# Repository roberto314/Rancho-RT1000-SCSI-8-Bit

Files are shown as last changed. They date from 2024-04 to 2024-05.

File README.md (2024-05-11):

# Rancho-RT1000-SCSI-8-Bit
Recreation of a bootable ISA 8-Bit SCSI Card.

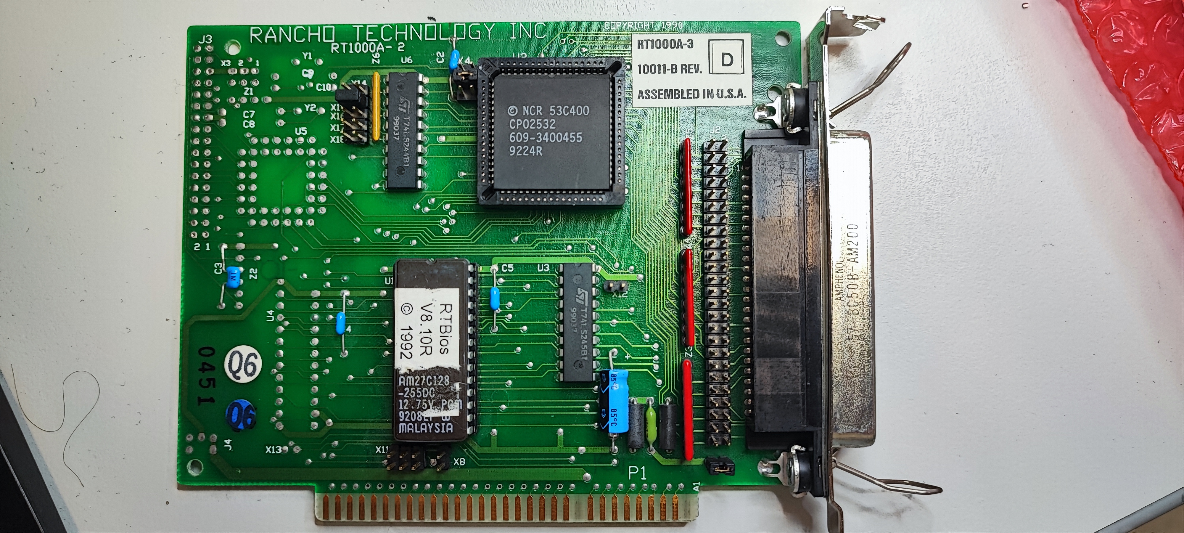
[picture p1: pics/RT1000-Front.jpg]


There can be one PAL on the Card (GAL20L8), this is for the floppy part only.
BIOS EPROM is a 27C128 Type, but only 8k are used.

[Schematic](schematic/Rancho%20RT1000/pdf/Rancho%20RT1000%20SCSI%20Controller.pdf)

For now there is no plan to manufacture the board.

| BIOS Ver. | 8088/80C88 | NEC V20 | 286 |  386SX |
|---|---|---|---|---|
| Rancho 8.10 | no boot, no ASPI | no boot, no ASPI | boots+ASPI | boots+ASPI |
| Rancho 8.20 | no boot, no ASPI | no boot, no ASPI | boots+ASPI | boots+ASPI |
| Corel 1.65  | no boot, Corel ASPI | boots+Corel ASPI | boots+ASPI | boots+ASPI |

Comment: On an XT, even with V20 CPU, with Rancho BIOS, a Disk is found but hangs when trying to boot. RTASPI10.SYS says it needs a 286.

The Card seems to be the same as the Corel LS2000, so i tried the Corel BIOS and it works!

Unfortunately the Corel uses a different CHS Conversion, so the Rancho Images won't work.

The ASPI Driver from the Rancho (RTASPI10.SYS) works with the Corel BIOS and vice versa, BUT they need the correct CHS Values!

The ASPI Driver from the Corel (ASPILS_D.SYS) works with a V20 CPU and with an 8088.
The ASPIDISK.SYS Driver doesn't like the 8088 BUT the Trantor TSCSI Disk Driver in Version 4.53 works (Filename: TSCSI.453)

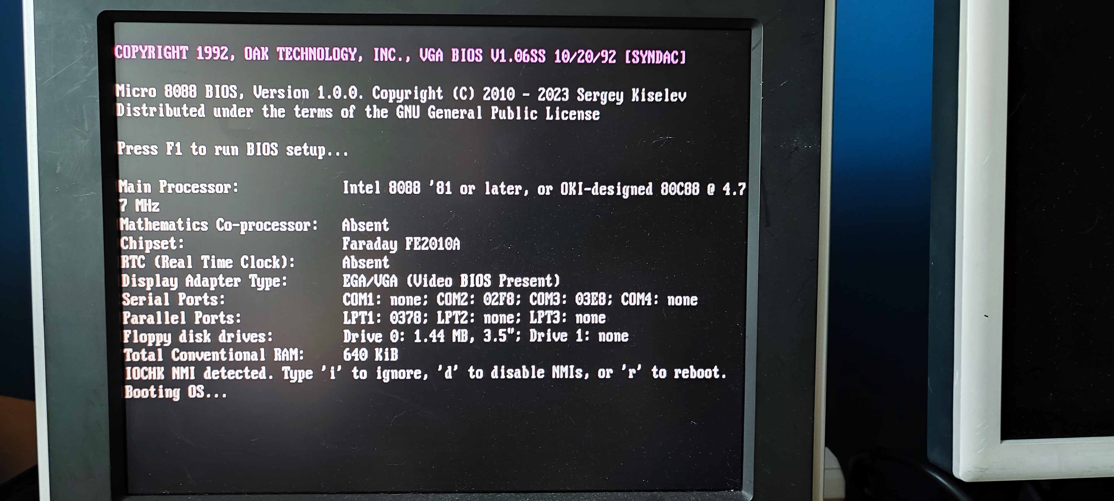
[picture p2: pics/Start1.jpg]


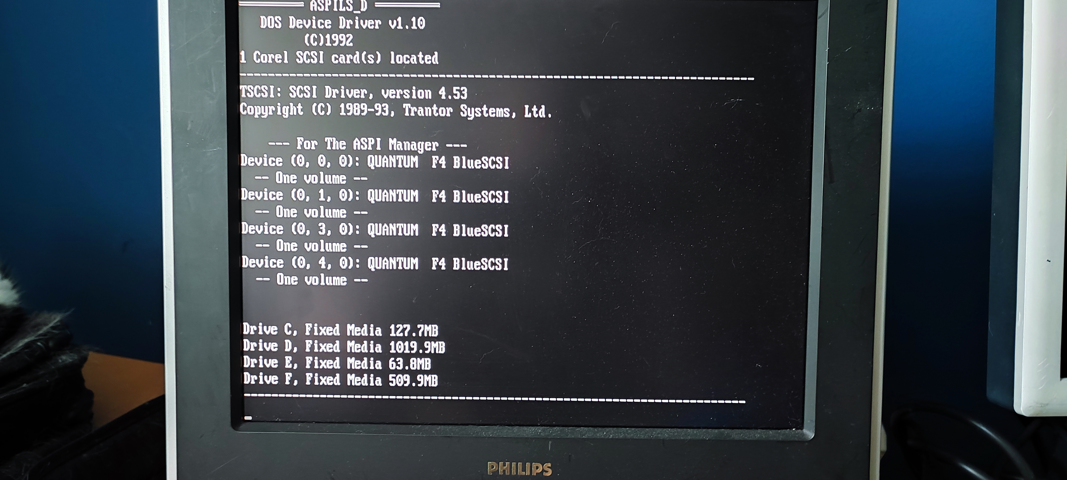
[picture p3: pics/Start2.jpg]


The Rancho BIOS doesn't need an Interrupt, the Corel BIOS seems to work only with IRQ4!
The Jumper X14, X15, X16, X17 and X18 won't do anything with the Corel BIOS.

With the BIOS EPROM installed the 8088 hangs during boot from Floppy! One has to disable the BIOS in order to boot on an 8088.

The Corel BIOS can only address two Harddisks without an ASPI Driver installed!

Heads and Sectors working with original RT1000 BIOS (v8.20):

Tested with MSDOS 5 and with a 386SX and does NOT work with an 8088 nor 80C88!:

(spc = Sectors/Cluster, spf = Sectors/FAT)

* C: 1023 / H:2  / S:32 32 MB (FAT16/4) spc=4,spf=0x40: works
* C: 1023 / H:4  / S:32 64 MB (FAT16/6) spc=4,spf=0x80: non-system disk
* C:  511 / H:8  / S:32 64 MB (FAT16/6) spc=4,spf=0x80: non-system disk
* C: 1015 / H:3  / S:43 65510 kB (FAT16/6) spc=4,spf=0x80: works
* C: 1023 / H:8  / S:32 128 MB (FAT16/6) spc=4,spf=0x100: non-system disk
* C: 1007 / H:5  / S:52 127.8 MB (FAT16/6) spc=4,spf=0x100: works
* C: 1021 / H:9  / S:57 261800 kB (FAT16/6) spc=8,spf=0x100: works
* C: 1023 / H:9  / S:57 262627 kB (FAT16/6) spc=16,spf=0x100: non-system disk
* C: 1010 / H:17  / S:60 515072 kB (FAT16/6) spc=16,spf=0xFC: works
* C: 1011 / H:31  / S:62 948 MB (FAT16/6) spc=32,spf=0xEE: works

Heads and Sectors working with Corel LS2000 BIOS (v1.65):

Tested with 386SX and does NOT work with an 8088!:

* C:  961 / H:17 / S:8 63.1 MB (FAT16/6) spc=4,spf=0x80: works
* C:  961 / H:17 / S:16 127.6 MB (FAT16/6) spc=4,spf=0xFF: works
* C: 1021 / H:32 / S:16 255.5 MB (FAT16/6) spc=16,spf=0x80: works
* C:  597 / H:64 / S:16 299 MB (FAT16/6) spc=16,spf=0x96: works
* C: 1003 / H:64 / S:16 502 MB (FAT16/6) spc=16,spf=0xFB: works
* C: 1019 / H:64 / S:16 509.9 MB (FAT16/6) spc=16,spf=0xFF: works
* C:  570 / H:64 / S:32 570.5 MB (FAT16/6) spc=32,spf=0x8F: works
* C:  571 / H:64 / S:32 572 MB (FAT16/6) spc=32,spf=0x8F: works
* C:  667 / H:64 / S:32 668 MB (FAT16/6) spc=32,spf=0xA7: works
* C:  762 / H:64 / S:32 763 MB (FAT16/6) spc=32,spf=0xBF: works
* C:  859 / H:64 / S:32 860 MB (FAT16/6) spc=32,spf=0xD7: works
* C:  903 / H:64 / S:32 904 MB (FAT16/6) spc=32,spf=0xE2: works
* C:  927 / H:64 / S:32 927.9 MB (FAT16/6) spc=32,spf=0xE8: works
* C: 1019 / H:64 / S:32 1020 MB (FAT16/6) spc=32,spf=0xFF: works
* C:  946 / H:64 / S:32 947 MB (FAT16/6) spc=32,spf=0xED: doesn't work
* C:  946 / H:64 / S:32 947 MB (FAT16/6) spc=32,spf=0xFB: doesn't work

It should be said that the Corel Drivers and BIOS is the way to go!

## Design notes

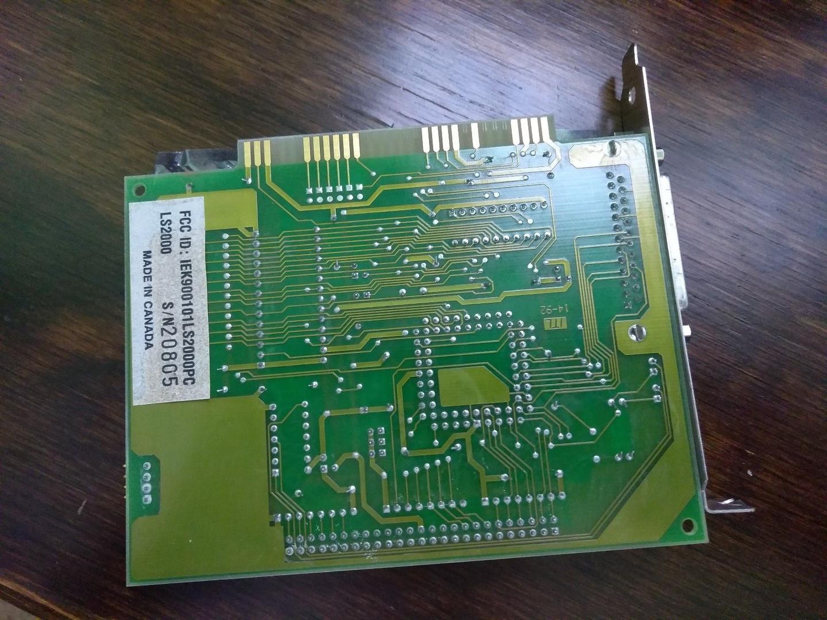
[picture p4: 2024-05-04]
pics/Back.jpg

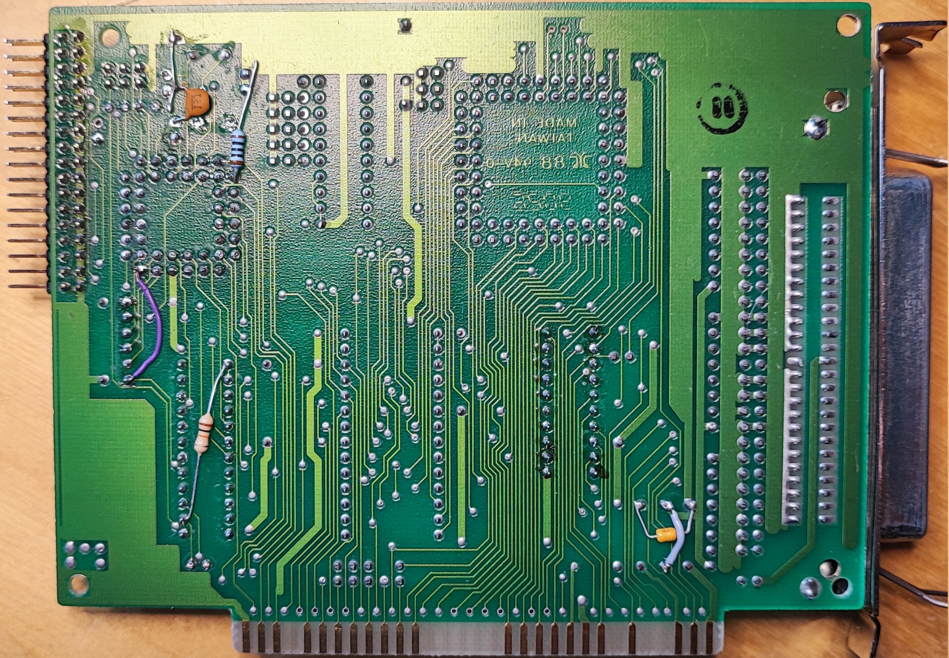
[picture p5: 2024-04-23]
pics/RT1000-Back.jpg

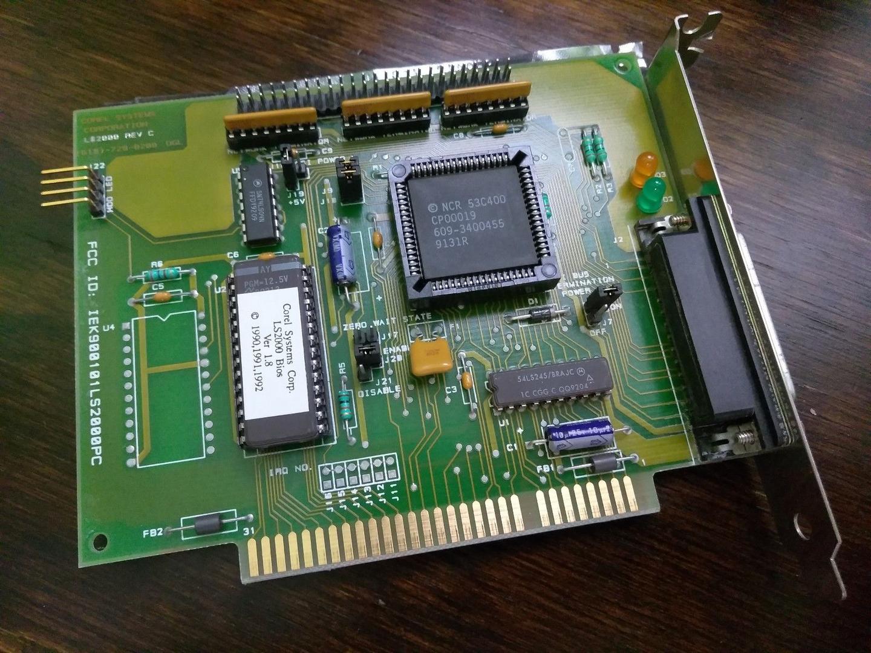
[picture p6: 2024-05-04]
pics/Front.jpg

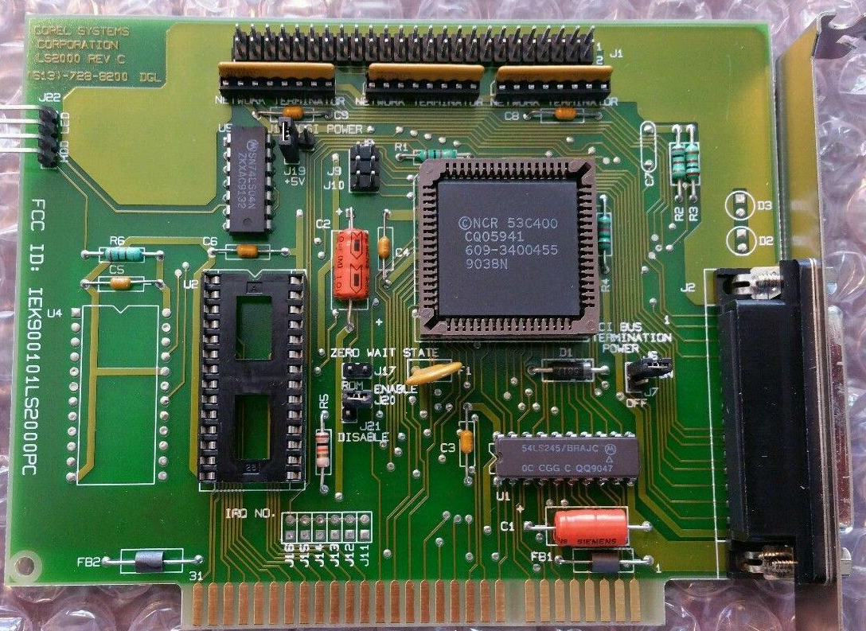
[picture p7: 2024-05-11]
pics/Corel LS2000 Front.png

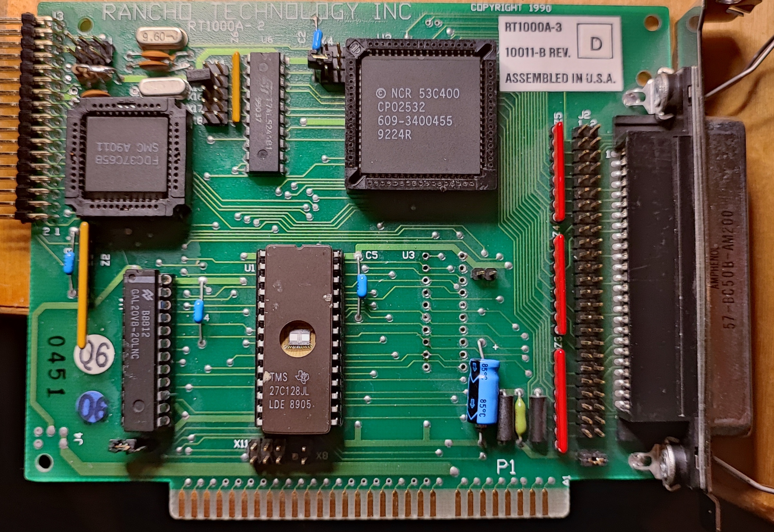
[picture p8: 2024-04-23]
pics/RT1000-Front_Floppy.jpg

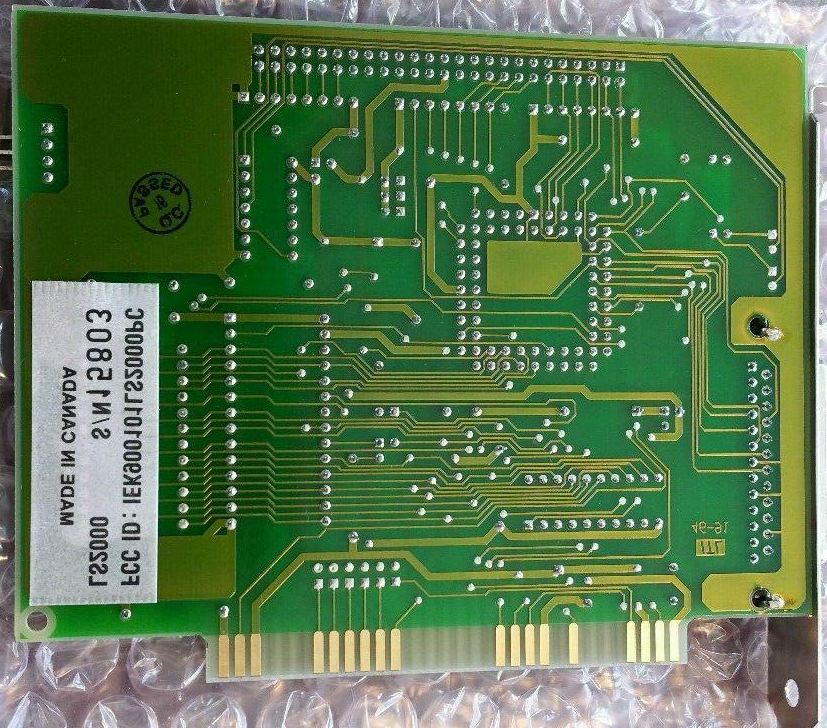
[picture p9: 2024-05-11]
pics/Corel LS2000 Back.png

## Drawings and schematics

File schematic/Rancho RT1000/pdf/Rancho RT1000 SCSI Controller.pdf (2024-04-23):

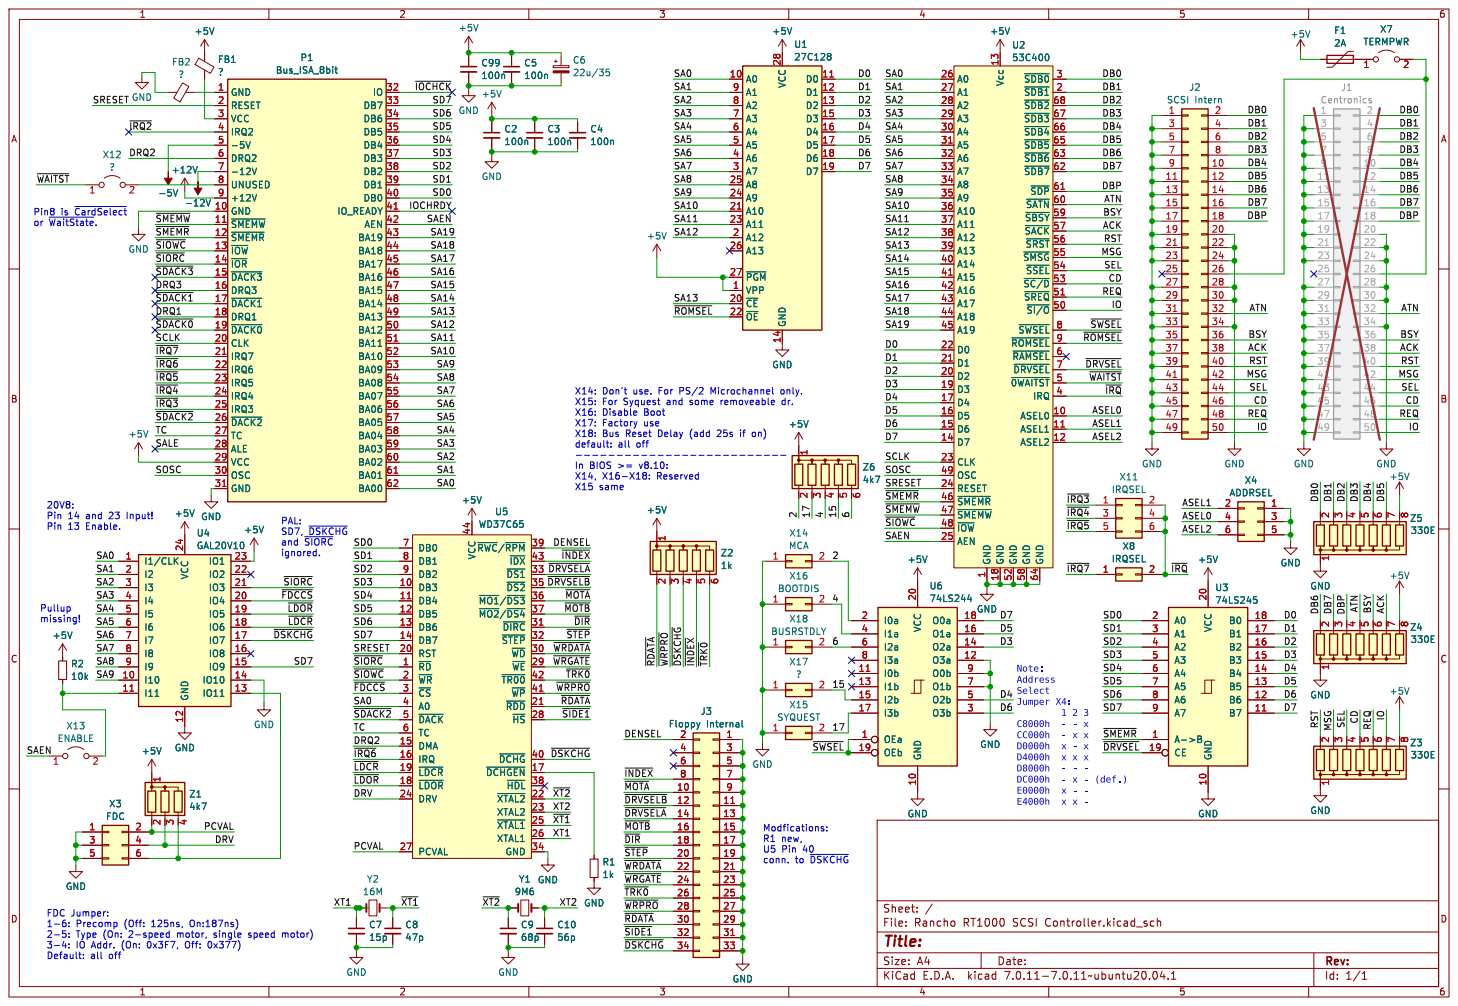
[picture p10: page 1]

1 ASEL0 10 ASEL1 11 ASEL2 12 Vcc 13 D7 14 D6 15 D5 16 D4 17 GND 18 D3 19 ~{SDB1}2 D2 20 D1 21 D0 22 CLK 23 RESET 24 AEN 25

~{SBSY} 59 ~{RAMSEL}6 ~{SATN} 60 ~{SDP} 61 ~{SDB7}62 ~{SDB6}63 GND 64

~{SC/D}53 ~{SSEL} 54 ~{SMSG} 55 ~{SRST} 56 ~{SACK} 57 GND 58

conn. to ~{DSKCHG} J3 Floppy Internal 1

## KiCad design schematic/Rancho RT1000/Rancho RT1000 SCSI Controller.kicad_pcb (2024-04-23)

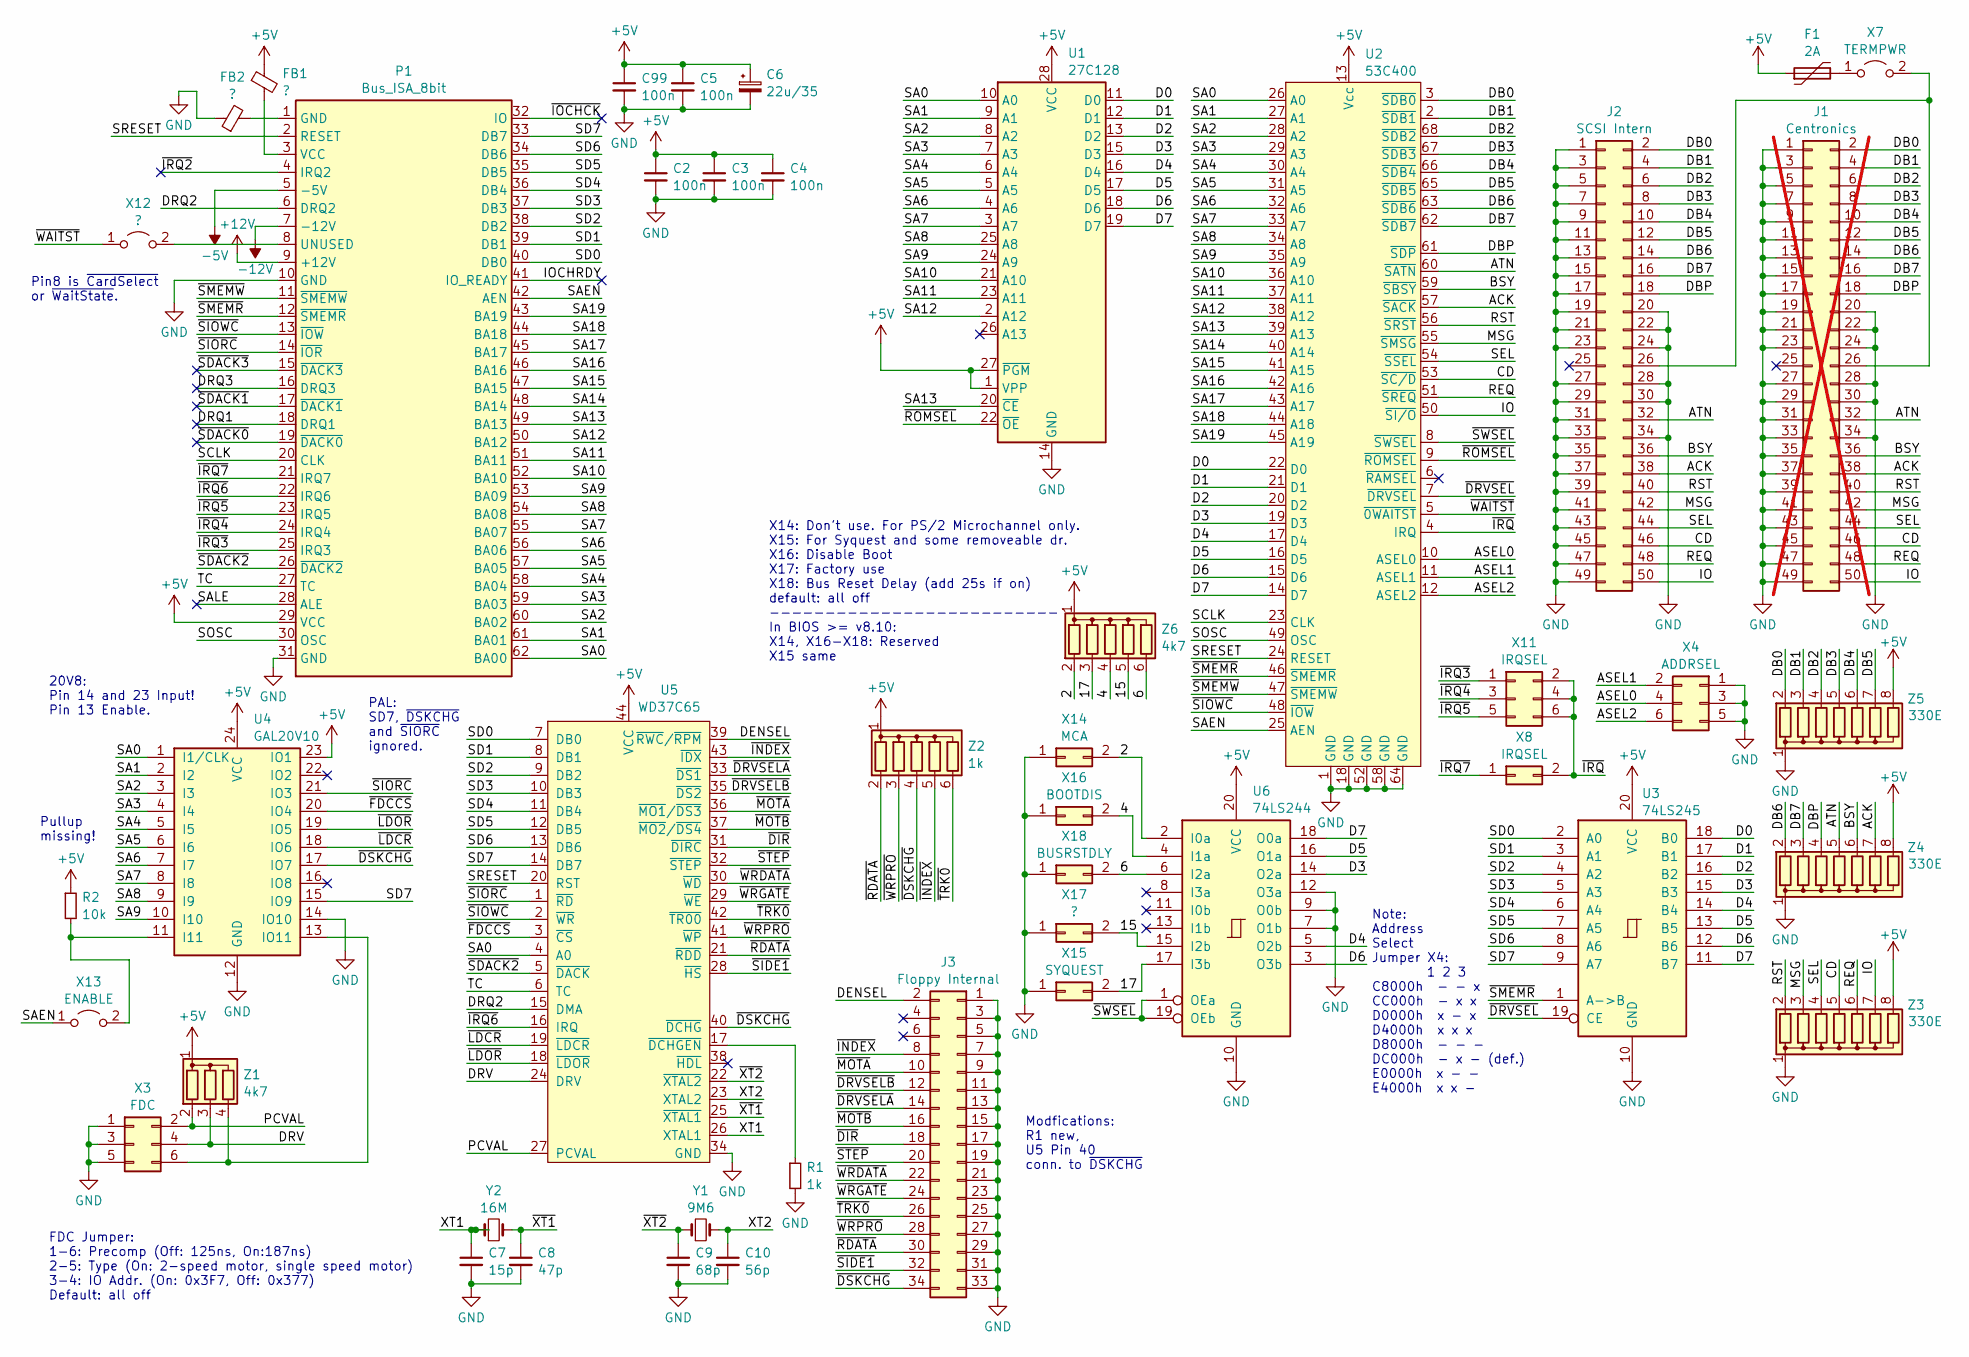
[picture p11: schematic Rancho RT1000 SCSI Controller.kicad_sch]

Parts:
C2, C3, C4, C5: 100n; C_Axial_L3.8mm_D2.6mm_P12.50mm_Horizontal
C6: 22u/35; C_Axial_L12.0mm_D6.5mm_P20.00mm_Horizontal
C7: 15p; C_Axial_L3.8mm_D2.6mm_P12.50mm_Horizontal
C8: 47p; C_Axial_L3.8mm_D2.6mm_P12.50mm_Horizontal
C9: 68p; C_Axial_L3.8mm_D2.6mm_P12.50mm_Horizontal
C10: 56p; C_Axial_L3.8mm_D2.6mm_P12.50mm_Horizontal
C99: 100n; C_Rect_L9.0mm_W2.5mm_P7.50mm_MKT
F1: 2A; L_Axial_L5.3mm_D2.2mm_P10.16mm_Horizontal_Vishay_IM-1
FB1, FB2: ?; L_Axial_L5.3mm_D2.2mm_P10.16mm_Horizontal_Vishay_IM-1
J1: Centronics; PinHeader_2x25_P2.54mm_Vertical; not fitted
J2: SCSI Intern; PinHeader_2x25_P2.54mm_Vertical
J3: Floppy Internal; PinHeader_2x17_P2.54mm_Vertical
P1: Bus_ISA_8bit; BUS_XT
R1: 1k; R_Axial_DIN0309_L9.0mm_D3.2mm_P12.70mm_Horizontal
R2: 10k; R_Axial_DIN0309_L9.0mm_D3.2mm_P12.70mm_Horizontal
U1: 27C128; DIP-28_W15.24mm_Socket_LongPads
U2: 53C400; PLCC-68_THT-Socket
U3: 74LS245; DIP-20_W7.62mm_LongPads
U4: GAL20V10; DIP-24_W7.62mm_Socket_LongPads
U5: WD37C65; PLCC-44_THT-Socket
U6: 74LS244; DIP-20_W7.62mm_LongPads
X3: FDC; PinHeader_2x03_P2.54mm_Vertical
X4: ADDRSEL; PinHeader_2x03_P2.54mm_Vertical
X7: TERMPWR; PinHeader_2x01_P2.54mm_Vertical
X8: IRQSEL; PinHeader_2x01_P2.54mm_Vertical
X11: IRQSEL; PinHeader_2x03_P2.54mm_Vertical
X12, X17: ?; PinHeader_2x01_P2.54mm_Vertical
X13: ENABLE; PinHeader_2x01_P2.54mm_Vertical
X14: MCA; PinHeader_2x01_P2.54mm_Vertical
X15: SYQUEST; PinHeader_2x01_P2.54mm_Vertical
X16: BOOTDIS; PinHeader_2x01_P2.54mm_Vertical
X18: BUSRSTDLY; PinHeader_2x01_P2.54mm_Vertical
Y1: 9M6; Crystal_HC49-U_Vertical
Y2: 16M; Crystal_HC49-U_Vertical
Z1: 4k7; R_Array_SIP4
Z2: 1k; R_Array_SIP6
Z3, Z4, Z5: 330E; R_Array_SIP8
Z6: 4k7; R_Array_SIP6

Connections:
+5V: C2.1, C3.1, C4.1, C5.1, C6.1, C99.1, F1.1, FB1.1, P1.29 (VCC), R2.1, U1.1 (VPP), U1.27 (~PGM), U1.28 (VCC), U2.13 (Vcc), U3.20 (VCC), U4.23 (IO1), U4.24 (VCC), U5.44 (VCC), U6.20 (VCC), Z1.1 (common), Z2.1 (common), Z3.8 (R7), Z4.8 (R7), Z5.8 (R7), Z6.1 (common)
+12V: P1.9 (+12V)
-5V: P1.5 (-5V)
-12V: P1.7 (-12V)
/2: U6.2 (I0a), X14.2, Z6.2 (R1)
/4: U6.4 (I1a), X16.2, Z6.4 (R3)
/6: U6.6 (I2a), X18.2, Z6.6 (R5)
/15: U6.15 (I2b), X17.2, Z6.5 (R4)
/17: U6.17 (I3b), X15.2, Z6.3 (R2)
/ACK: J1.38, J2.38, U2.57 (~SACK), Z4.7 (R6)
/ASEL0: U2.10 (ASEL0), X4.4
/ASEL1: U2.11 (ASEL1), X4.2
/ASEL2: U2.12 (ASEL2), X4.6
/ATN: J1.32, J2.32, U2.60 (~SATN), Z4.5 (R4)
/BSY: J1.36, J2.36, U2.59 (~SBSY), Z4.6 (R5)
/CD: J1.46, J2.46, U2.53 (~SC/D), Z3.5 (R4)
/D0: U1.11 (D0), U2.22 (D0), U3.18 (B0)
/D1: U1.12 (D1), U2.21 (D1), U3.17 (B1)
/D2: U1.13 (D2), U2.20 (D2), U3.16 (B2)
/D3: U1.15 (D3), U2.19 (D3), U3.15 (B3), U6.14 (O2a)
/D4: U1.16 (D4), U2.17 (D4), U3.14 (B4), U6.5 (O2b)
/D5: U1.17 (D5), U2.16 (D5), U3.13 (B5), U6.16 (O1a)
/D6: U1.18 (D6), U2.15 (D6), U3.12 (B6), U6.3 (O3b)
/D7: U1.19 (D7), U2.14 (D7), U3.11 (B7), U6.18 (O0a)
/DB0: J1.2, J2.2, U2.3 (~SDB0), Z5.2 (R1)
/DB1: J1.4, J2.4, U2.2 (~SDB1), Z5.3 (R2)
/DB2: J1.6, J2.6, U2.68 (~SDB2), Z5.4 (R3)
/DB3: J1.8, J2.8, U2.67 (~SDB3), Z5.5 (R4)
/DB4: J1.10, J2.10, U2.66 (~SDB4), Z5.6 (R5)
/DB5: J1.12, J2.12, U2.65 (~SDB5), Z5.7 (R6)
/DB6: J1.14, J2.14, U2.63 (~SDB6), Z4.2 (R1)
/DB7: J1.16, J2.16, U2.62 (~SDB7), Z4.3 (R2)
/DBP: J1.18, J2.18, U2.61 (~SDP), Z4.4 (R3)
/DENSEL: J3.2, U5.39 (~RWC/~RPM)
/DRQ1: P1.18 (DRQ1)
/DRQ2: P1.6 (DRQ2), U5.15 (DMA)
/DRQ3: P1.16 (DRQ3)
/DRV: U5.24 (DRV), X3.4, Z1.3 (R2)
/IO: J1.50, J2.50, U2.50 (~SI/O), Z3.7 (R6)
/IOCHRDY: P1.41 (IO_READY)
/MSG: J1.42, J2.42, U2.55 (~SMSG), Z3.3 (R2)
/PCVAL: U5.27 (PCVAL), X3.2, Z1.2 (R1)
/REQ: J1.48, J2.48, U2.51 (~SREQ), Z3.6 (R5)
/RST: J1.40, J2.40, U2.56 (~SRST), Z3.2 (R1)
/SA0: P1.62 (BA00), U1.10 (A0), U2.26 (A0), U4.1 (I1/CLK), U5.4 (A0)
/SA1: P1.61 (BA01), U1.9 (A1), U2.27 (A1), U4.2 (I2)
/SA2: P1.60 (BA02), U1.8 (A2), U2.28 (A2), U4.3 (I3)
/SA3: P1.59 (BA03), U1.7 (A3), U2.29 (A3), U4.4 (I4)
/SA4: P1.58 (BA04), U1.6 (A4), U2.30 (A4), U4.5 (I5)
/SA5: P1.57 (BA05), U1.5 (A5), U2.31 (A5), U4.6 (I6)
/SA6: P1.56 (BA06), U1.4 (A6), U2.32 (A6), U4.7 (I7)
/SA7: P1.55 (BA07), U1.3 (A7), U2.33 (A7), U4.8 (I8)
/SA8: P1.54 (BA08), U1.25 (A8), U2.34 (A8), U4.9 (I9)
/SA9: P1.53 (BA09), U1.24 (A9), U2.35 (A9), U4.10 (I10)
/SA10: P1.52 (BA10), U1.21 (A10), U2.36 (A10)
/SA11: P1.51 (BA11), U1.23 (A11), U2.37 (A11)
/SA12: P1.50 (BA12), U1.2 (A12), U2.38 (A12)
/SA13: P1.49 (BA13), U1.20 (~CE), U2.39 (A13)
/SA14: P1.48 (BA14), U2.40 (A14)
/SA15: P1.47 (BA15), U2.41 (A15)
/SA16: P1.46 (BA16), U2.42 (A16)
/SA17: P1.45 (BA17), U2.43 (A17)
/SA18: P1.44 (BA18), U2.44 (A18)
/SA19: P1.43 (BA19), U2.45 (A19)
/SAEN: P1.42 (AEN), U2.25 (AEN), X13.1 (A)
/SALE: P1.28 (ALE)
/SCLK: P1.20 (CLK), U2.23 (CLK)
/SD0: P1.40 (DB0), U3.2 (A0), U5.7 (DB0)
/SD1: P1.39 (DB1), U3.3 (A1), U5.8 (DB1)
/SD2: P1.38 (DB2), U3.4 (A2), U5.9 (DB2)
/SD3: P1.37 (DB3), U3.5 (A3), U5.10 (DB3)
/SD4: P1.36 (DB4), U3.6 (A4), U5.11 (DB4)
/SD5: P1.35 (DB5), U3.7 (A5), U5.12 (DB5)
/SD6: P1.34 (DB6), U3.8 (A6), U5.13 (DB6)
/SD7: P1.33 (DB7), U3.9 (A7), U4.15 (IO9), U5.14 (DB7)
/SEL: J1.44, J2.44, U2.54 (~SSEL), Z3.4 (R3)
/SOSC: P1.30 (OSC), U2.49 (OSC)
/SRESET: P1.2 (RESET), U2.24 (RESET), U5.20 (RST)
/TC: P1.27 (TC), U5.6 (TC)
/XT1: C7.1, U5.26 (XTAL1), Y2.1
/XT2: C10.1, U5.23 (XTAL2), Y1.2
/~DIR: J3.18, U5.31 (~DIRC)
/~DRVSELA: J3.14, U5.33 (~DS1)
/~DRVSELB: J3.12, U5.35 (~DS2)
/~DRVSEL: U2.7 (~DRVSEL), U3.19 (CE)
/~DSKCHG: J3.34, U4.17 (IO7), U5.40 (~DCHG), Z2.4 (R3)
/~FDCCS: U4.20 (IO4), U5.3 (~CS)
/~INDEX: J3.8, U5.43 (~IDX), Z2.5 (R4)
/~IOCHCK: P1.32 (IO)
/~IRQ2: P1.4 (IRQ2)
/~IRQ3: P1.25 (IRQ3), X11.1
/~IRQ4: P1.24 (IRQ4), X11.3
/~IRQ5: P1.23 (IRQ5), X11.5
/~IRQ6: P1.22 (IRQ6), U5.16 (IRQ)
/~IRQ7: P1.21 (IRQ7), X8.1
/~IRQ: U2.4 (IRQ), X8.2, X11.2, X11.4, X11.6
/~LDCR: U4.18 (IO6), U5.19 (~LDCR)
/~LDOR: U4.19 (IO5), U5.18 (~LDOR)
/~MOTA: J3.10, U5.36 (~MO1/~DS3)
/~MOTB: J3.16, U5.37 (~MO2/~DS4)
/~RDATA: J3.30, U5.21 (~RDD), Z2.2 (R1)
/~ROMSEL: U1.22 (~OE), U2.9 (~ROMSEL)
/~SDACK0: P1.19 (~DACK0)
/~SDACK1: P1.17 (~DACK1)
/~SDACK2: P1.26 (~DACK2), U5.5 (~DACK)
/~SDACK3: P1.15 (~DACK3)
/~SIDE1: J3.32, U5.28 (~HS)
/~SIORC: P1.14 (~IOR), U4.21 (IO3), U5.1 (~RD)
/~SIOWC: P1.13 (~IOW), U2.48 (~IOW), U5.2 (~WR)
/~SMEMR: P1.12 (~SMEMR), U2.46 (~SMEMR), U3.1 (A->B)
/~SMEMW: P1.11 (~SMEMW), U2.47 (~SMEMW)
/~STEP: J3.20, U5.32 (~STEP)
/~SWSEL: U2.8 (~SWSEL), U6.1 (OEa), U6.19 (OEb)
/~TRK0: J3.26, U5.42 (~TR00), Z2.6 (R5)
/~WAITST: U2.5 (~0WAITST), X12.1 (A)
/~WRDATA: J3.22, U5.30 (~WD)
/~WRGATE: J3.24, U5.29 (~WE)
/~WRPRO: J3.28, U5.41 (~WP), Z2.3 (R2)
/~XT1: C8.1, U5.25 (~XTAL1), Y2.2
/~XT2: C9.1, U5.22 (~XTAL2), Y1.1
GND: C2.2, C3.2, C4.2, C5.2, C6.2, C7.2, C8.2, C9.2, C10.2, C99.2, FB2.1, J1.1, J1.3, J1.5, J1.7, J1.9, J1.11, J1.13, J1.15, J1.17, J1.19, J1.20, J1.21, J1.22, J1.23, J1.24, J1.27, J1.28, J1.29, J1.30, J1.31, J1.33, J1.34, J1.35, J1.37, J1.39, J1.41, J1.43, J1.45, J1.47, J1.49, J2.1, J2.3, J2.5, J2.7, J2.9, J2.11, J2.13, J2.15, J2.17, J2.19, J2.20, J2.21, J2.22, J2.23, J2.24, J2.27, J2.28, J2.29, J2.30, J2.31, J2.33, J2.34, J2.35, J2.37, J2.39, J2.41, J2.43, J2.45, J2.47, J2.49, J3.1, J3.3, J3.5, J3.7, J3.9, J3.11, J3.13, J3.15, J3.17, J3.19, J3.21, J3.23, J3.25, J3.27, J3.29, J3.31, J3.33, P1.10 (GND), P1.31 (GND), R1.2, U1.14 (GND), U2.1 (GND), U2.18 (GND), U2.52 (GND), U2.58 (GND), U2.64 (GND), U3.10 (GND), U4.12 (GND), U4.14 (IO10), U5.34 (GND), U6.7 (O1b), U6.9 (O0b), U6.10 (GND), U6.12 (O3a), X3.1, X3.3, X3.5, X4.1, X4.3, X4.5, X14.1, X15.1, X16.1, X17.1, X18.1, Z3.1 (common), Z4.1 (common), Z5.1 (common)
unnamed: FB1.2, P1.3 (VCC)
unnamed: FB2.2, P1.1 (GND)
unnamed: J1.26, J2.26, X7.2 (B)
unnamed: P1.8 (UNUSED), X12.2 (B)
unnamed: R2.2, U4.11 (I11), X13.2 (B)
unnamed: U4.13 (IO11), X3.6, Z1.4 (R3)
unnamed: R1.1, U5.17 (~DCHGEN)
unnamed: F1.2, X7.1 (A)

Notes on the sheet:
Pullup missing!
X14: Don't use. For PS/2 Microchannel only. X15: For Syquest and some removeable dr. X16: Disable Boot X17: Factory use X18: Bus Reset Delay (add 25s if on) default: all off -------------------------- In BIOS >= v8.10: X14, X16-X18: Reserved X15 same
FDC Jumper: 1-6: Precomp (Off: 125ns, On:187ns) 2-5: Type (On: 2-speed motor, single speed motor) 3-4: IO Addr. (On: 0x3F7, Off: 0x377) Default: all off
Modfications: R1 new, U5 Pin 40 conn. to ~{DSKCHG}
Note: Address Select Jumper X4: 1 2 3 C8000h - - x CC000h - x x D0000h x - x D4000h x x x D8000h - - - DC000h - x - (def.) E0000h x - - E4000h x x -
PAL: SD7, ~{DSKCHG} and ~{SIORC} ignored.
Pin8 is ~{CardSelect} or ~{WaitState}.
20V8: Pin 14 and 23 Input! Pin 13 Enable.

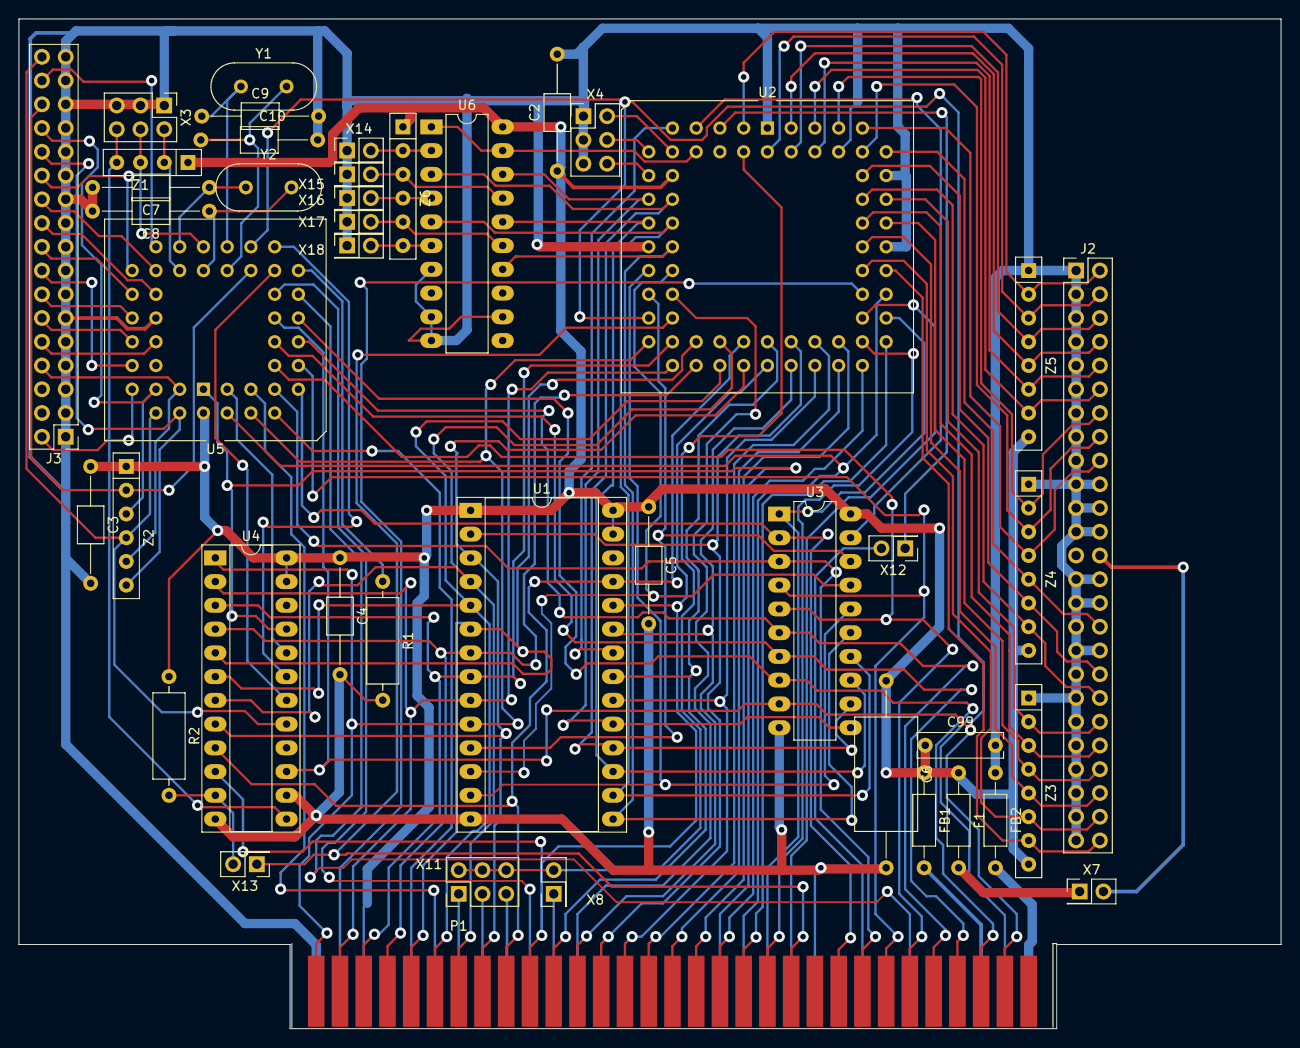
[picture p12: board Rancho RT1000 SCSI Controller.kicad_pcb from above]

Board: 2 copper layers, 135.0 x 108.0 mm, 44 parts (0 on the bottom side), 117 nets.
